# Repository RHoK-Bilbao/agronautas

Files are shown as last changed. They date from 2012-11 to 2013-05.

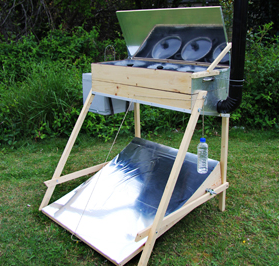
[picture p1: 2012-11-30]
software/web/assets/imgs/coc_demo.png

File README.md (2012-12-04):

RHoK-Bilbao 2012 (@rhokbilbao) project for ecologic solar cookers (Problem proposed by @pezestudio)

The solar cookers have an arduino board that connects to a central server to update information about its usage.

This information is then shared as Linked Open Data and visualized in a web interface 

!!!!!!!!!!!!!!!!!!!!!!!!!NOTE!!!!!!!!!!!!!!!!!!!!!!!!!!!!!!!!!

We have to upload still some of the code and the PCB designs. We hope to have them finished before christmass, be patient :-)

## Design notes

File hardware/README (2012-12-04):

This directory contains all the Arduino related files
	- agrococinas_sw contains the code for arduino
	- circuits contains all the PCB designs
	- models contains all the designs for the 3D printers
	
TODO: upload the models and PCB designs

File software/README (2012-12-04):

Non-Arduino software of the project.
	- lod contains the python server that receives the notificatios from the solar cookers. The servers converts this info to rdf and stores it in a Virtuoso server
	- web contains the web-interface for visualizing all the data

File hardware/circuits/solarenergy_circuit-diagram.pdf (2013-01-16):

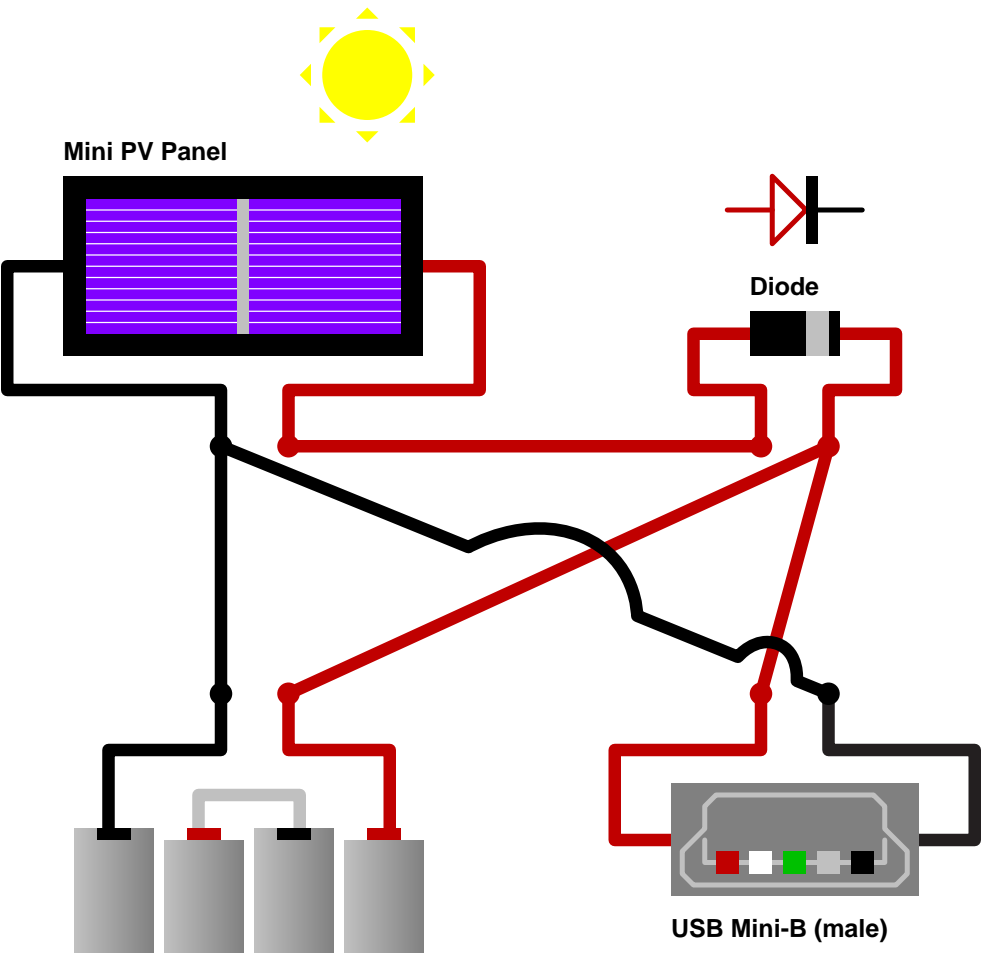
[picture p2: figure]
USB Mini-B (male); Mini PV Panel; Diode

NiMH DC Power Source

http://neotoy.tripod.com/
neotoy@hotmail.com

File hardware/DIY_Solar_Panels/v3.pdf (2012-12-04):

## Design v3.0

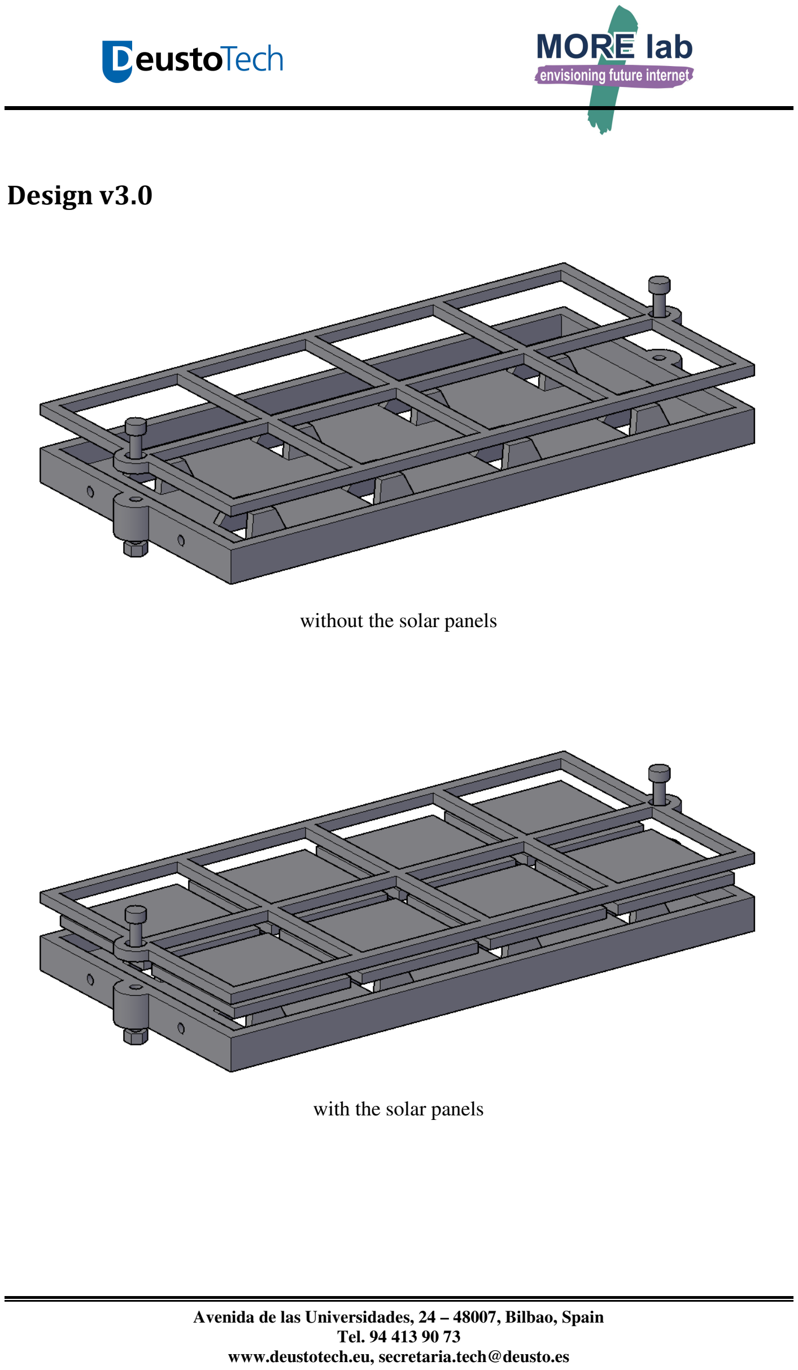
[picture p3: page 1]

Avenida de las Universidades, 24 – 48007, Bilbao, Spain Tel. 94 413 90 73
www.deustotech.eu, secretaria.tech@deusto.es

### without the solar panels

### with the solar panels

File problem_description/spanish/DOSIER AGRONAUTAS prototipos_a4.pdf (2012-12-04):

# agronautas

# pez

estudio

## Exploraciones entre personas y medio natural

un proyecto desarrollado por: | financia:

Juan
Dopico
Massobrio

+

## prototipos construidos

# proyectoagronautas

[AGRONAUTAS] es un proyecto multidisciplinar que investiga en procesos, diseños e iniciativas que reformulan la relación entre las personas y el medio natural.

+¿qué es?

+objetivos

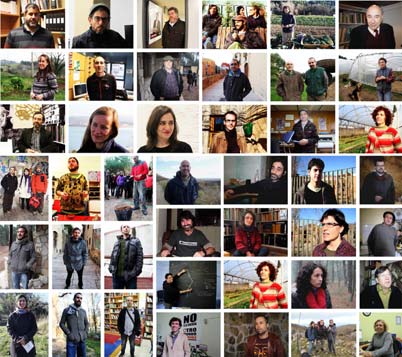
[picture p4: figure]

+herramientas

herramientas (cont.)

+Utilizar las tecnologías de la información, los recursos audiovisuales y medios digitales para socializar y extender modos de vida sostenible en los cuales se minimiza el consumo de energía y recursos.

+Poner en valor creaciones y modos de vida de profesionales y comunidades que, aunque representan avances en términos de sostenibilidad, no son normalmente visibles por la población.

+Realizar innovaciones en cuanto a minimización en consumo de recursos y energía a través de proyectos concretos y objetos o arquitecturas construidas.

o[EXPLORAR]
Se analizan y documentan iniciativas basadas en la minimización del impacto humano, así como del consumo de recursos y energía, en favor de un beneficio colectivo. Se trata de poner en valor proyectos que, pese a su interés, pueden pasar inadvertidos.

o[DESARROLLO AUDIOVISUAL]
A partir de la información recogida, se elaboran discursos audiovisuales que recojen experiencias y opiniones de los profesionales y colectivos entrevistados ,cuya actividad resulta muy interesante y, a veces, poco visible.
Se han documentado y registrado 40 experiencias colectivas, un total de 56 personas que desarrollan proyectos o modos de vida innovadores respecto al medio natural, a nivel individual, en comunidades o a través de su actividad profesional. En la primera etapa de exploración se ha realizado un documental recogiendo los mejores momentos de estas entrevistas.

o[TALLER COLABORATIVO]
Se desarrollan talleres constructivos para diseñar colaborativamente infraestructuras de beneficio colectivo en el marco de investigación del proyecto.
El primer taller constructivo dio lugar al primer prototipo de Agrococina, mobiliario compartido para huertas comunitarias y espacios exteriores.
Las infraestructuras se construyen en colaboración con comunidades que sean usuarios potenciales de lo construido, respondiendo a unas necesidades concretas.

o[EVALUAR]
Los prototipos se ponen en carga a través de los usuarios generados en la red del taller de construcción.

o[COMPARTIR]
Toda la información técnica y manuales se comparte en la red para que los prototipos sean evolucionados colectivamente. Agronautas abre un espacio físico y virtual de interacción.

o[AUTOGESTIONAR]
Las infraestructuras son totalmente asumidas y apropiadas por las comunidades que las adaptarán o modificarán según sus necesidades.

introducción

a

### Prototipos Construidos de

## agrococina

## ecomobiliario compartido

# pez

estudio

un proyecto desarrollado por: | financia:

Juan
Dopico
Massobrio

+

# agrococinabilbao 1

[AGROCOCINA] es un concepto de experiencia ecológica integral basado en el diseño de infraestructuras relacionadas con la arquitectura, la gastronomía, las artes culinarias, la ecología y la sociedad. El proyecto trabaja sobre el respeto al Medio Ambiente a través de los siguientes valores:
_Apoyar la producción ecológica y local, dando lugar a infraestructuras que faciliten y potencien estas prácticas. _Minimizar el uso de recursos en la construcción, utilizando metodologías y materiales de origen ecológico.
_Tender al gasto 0 de energía a través del desarrollo y mejora de sistemas y tecnologías renovables y novedosas. _Elaborar técnicas culinarias innovadoras, como recetas especialmente adecuadas al uso de fuentes de energía renovables.
_Potenciar la colectividad en torno a las experiencias relacionadas con la alimentación, la cocina y el acto de comer con diferentes grupos de personas y vinculando diferentes actividades.

El primer prototipo de Agrococina se concibió como un mobiliario completo diseñado para su uso en huertos comunitarios y pensado para ser reproducible de manera autoconstruida y evolucionada de forma colectiva.

Se construyó en Bilbao a través de sesiones previas con expertos y un taller colaborativo en el que se involucraron diferentes colectivos, usuarios de huertos colectivos de la ciudad y participantes.

El resultado ya ha empezado a ser utilizado y testado por distintos usuarios de diferentes huertos y asociaciones .
El prototipo incluye un sistema de monitorización vinculado a un software web que permite el almacenamiento y la compartición de datos en la red. El objetivo es realizar un seguimiento de éste y otros prototipos, permitiendo su comparación online y mejorarando su uso y diseño a lo largo del tiempo.
+¿qué es? | +primer prototipo | +testeo y monitorización

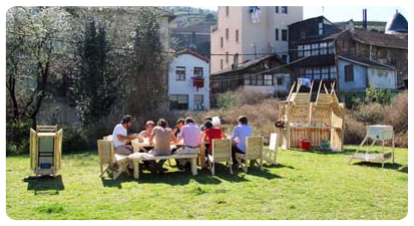
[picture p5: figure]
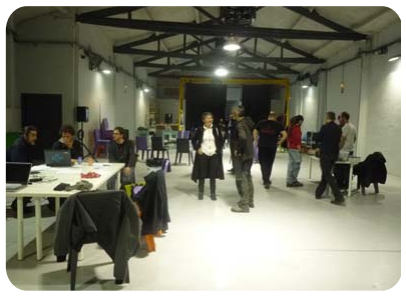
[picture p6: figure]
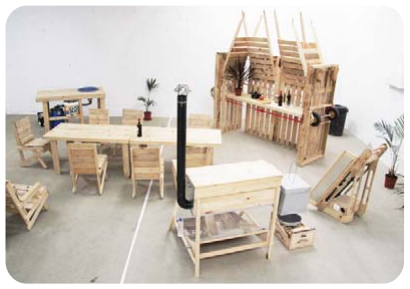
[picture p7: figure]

Para el diseño y construcción del primer prototipo, Pez[estudio] generó un equipo de trabajo multidisciplinar con expertos vinculados a los diferentes temas a desarrollar:

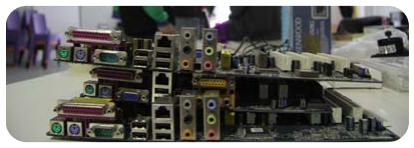
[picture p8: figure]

o[DISEÑO GLOBAL Y ORGANIZACIÓN]
+PEZ[estudio], | célula | creativa | de | arquitectura.
Desarrollamos proyectos de investigación, acción y diseño a diferentes escalas, con líneas de trabajo como la minimización de impacto sobre el medioambiente, la participación ciudadana o las técnicas y tecnologías no estandarizadas. http://www.pezestudio.org/

o[MÁQUINA DE COCINAR]
+TaerSolar es una empresa formada por especialistas en las nuevas tecnologías relacionadas con las energías renovables. http://www.taersolar.net/
+“Súper” es un experto reconocido a nivel internacional en
construcciones | sostenibles | y | de | energía | solar.
http://www.solarquedada.net/

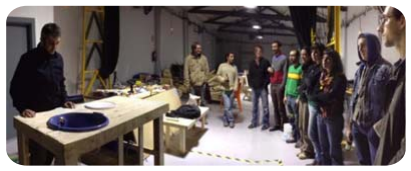
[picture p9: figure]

o[MOBILIARIO]
+Raumlabor berlin es un colectivo alemán que trabaja en la intersección entre la arquitectura, el planeamiento urbano, el arte y la intervención urbana. http://www.raumlabor.net

o[SISTEMA DE TRATAMIENTO Y DEPURACIÓN DE AGUA] +Mazetas desarrolla proyectos de arquitectura y paisaje con un enfoque ecológico sobre la gestión de los recursos y los residuos. http://mazetas.com/

o[ENERGÍA]
+Tuni Panea artista que especializado en electrónica, la música y el diseño. http://tunipanea.wordpress.com/(+Re:farm the city)

o[DISPOSITIVOS, WEB y VISUALIZACIÓN DE DATOS] +Re:farm the city provee de herramientas y conocimientos para diseñar, monitorizar, gestionar y compartir huertos urbanos. http://refarmthecity.org/

+equipo

# agronautas pez estudio

concepto

equipo (cont.)

### cocina-hornO SOLAR

### cocina-vapor solar

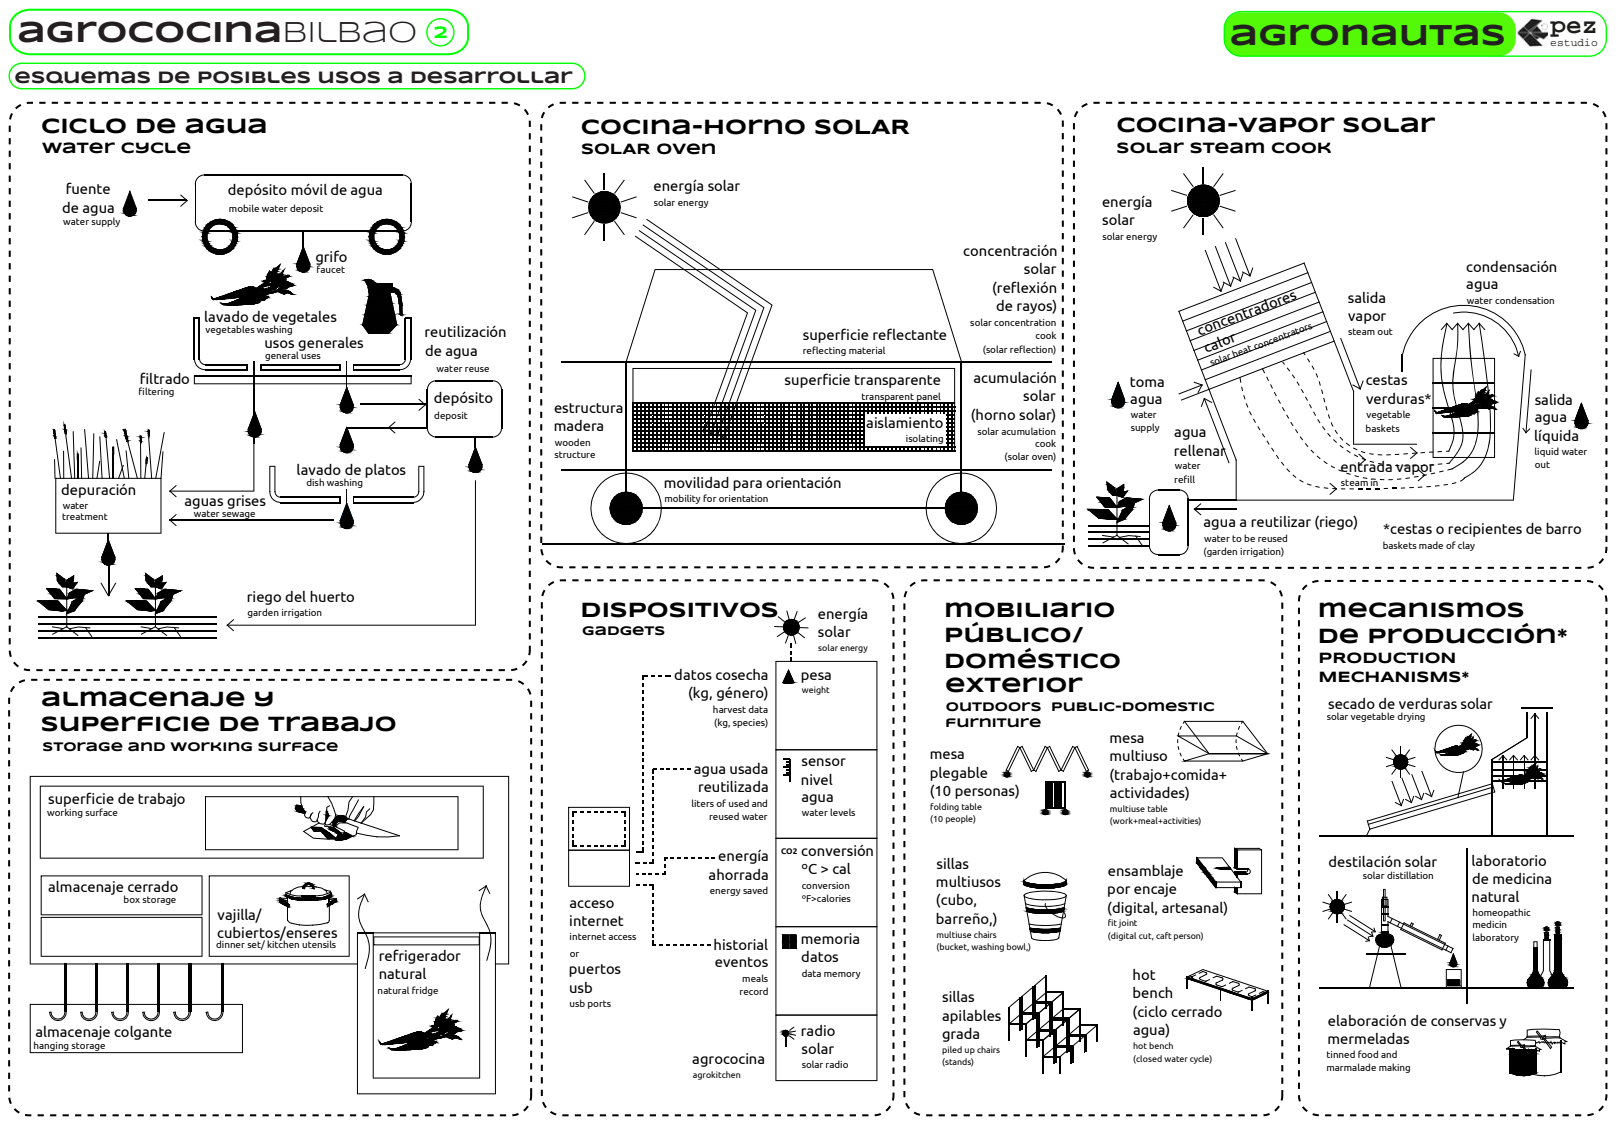
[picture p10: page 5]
SOLAR oven; energía solar; solar energy; acumulación solar (horno solar); concentración solar (reflexión de rayos); solar concentration cook (solar reflection); aislamiento; isolating; estructura madera; wooden structure; superficie transparente; transparent panel; superficie reflectante; reflecting material; toma agua; water supply; entrada vapor; steam in; cestas verduras*; vegetable baskets agua rellenar; water refill; salida agua líquida; liquid water out; condensación agua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

esquemas de posibles usos a desarrollar

ciclo de agua
water cycle

solar steam cook

depósito móvil de agua
mobile water deposit

concentradores calor solar heat concentrators salida vapor steam out

lavado de vegetales
vegetables washing

lavado de platos
dish washing

movilidad para orientación
mobility for orientation

agua a reutilizar (riego)
water to be reused
(garden irrigation)

*cestas o recipientes de barro
baskets made of clay

riego del huerto
garden irrigation

PRODUCTION
MECHANISMS*
secado de verduras solar
solar vegetable drying

almacenaje y
superficie de trabajo

storage and working surface

agua usada
reutilizada
liters of used and
reused water

working surface

multiuse table
(work+meal+activities)

vajilla/
cubiertos/enseres dinner set/ kitchen utensils

fit joint
(digital cut, caft person)

multiuse chairs
(bucket, washing bowl,)

elaboración de conservas y
mermeladas
tinned food and
marmalade making

piled up chairs
(stands)

hot bench
(closed water cycle)

agronautas | pez agrococinabilbao | estudio 3

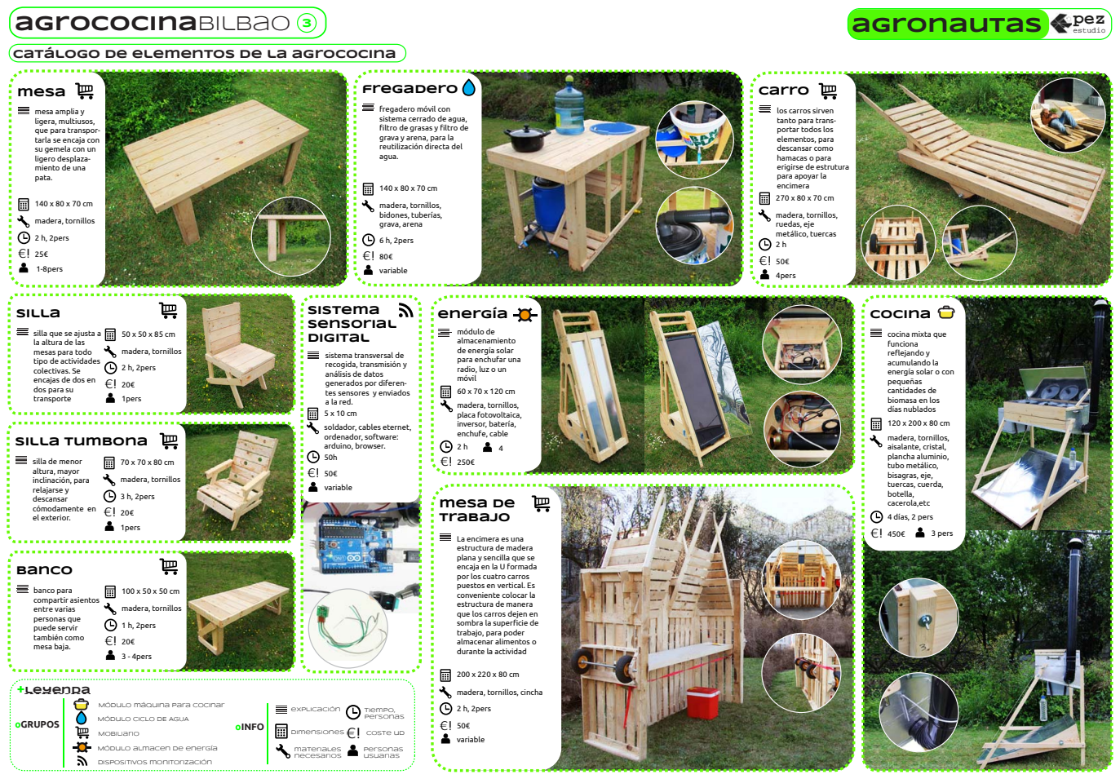
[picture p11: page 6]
carro; madera, tornillos, ruedas, eje metálico, tuercas 2 h; 4pers; mesa; madera, tornillos; 2 h, 2pers; 1-8pers; banco; 1 h, 2pers; 3 - 4pers; banco para compartir asientos entre varias personas que puede servir también como mesa baja.; fregadero; madera, tornillos, bidones, tuberías, grava, arena; 6 h, 2pers; variable; mesa de trabajo; madera, tornillos, cincha; cocina; 3 pers; energía; 4 silla tumbona; 3 h, 2pers; 1pers; silla; +leyenda; oGRUPOS; oINFO; materiales necesarios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

catálogo de elementos de la agrococina

mesa amplia y
ligera, multiusos,
que para transpor-
tarla se encaja con
su gemela con un
ligero desplaza-
miento de una
pata.

fregadero móvil con
sistema cerrado de agua,
filtro de grasas y filtro de
grava y arena, para la
reutilización directa del
agua.

los carros sirven
tanto para trans-
portar todos los
elementos, para
descansar como
hamacas o para
erigirse de estrutura
para apoyar la
encimera

silla que se ajusta a
la altura de las
mesas para todo
tipo de actividades
colectivas. Se
encajas de dos en
dos para su
transporte

módulo de
almacenamiento
de energía solar
para enchufar una
radio, luz o un
móvil
madera, tornillos,
placa fotovoltaica,
inversor, batería,
enchufe, cable

cocina mixta que
funciona
reflejando y
acumulando la
energía solar o con
pequeñas
cantidades de
biomasa en los
días nublados
aisalante, cristal,
plancha aluminio,
tubo metálico,
bisagras, eje,
tuercas, cuerda,
botella,
cacerola,etc
4 días, 2 pers

sistema transversal de
recogida, transmisión y
análisis de datos
generados por diferen-
tes sensores y enviados
a la red.
soldador, cables eternet,
ordenador, software:
arduino, browser.
variable

silla de menor
altura, mayor
inclinación, para
relajarse y
descansar
cómodamente en
el exterior.

La encimera es una
estructura de madera
plana y sencilla que se
encaja en la U formada
por los cuatro carros
puestos en vertical. Es
conveniente colocar la
estructura de manera
que los carros dejen en
sombra la superficie de
trabajo, para poder
almacenar alimentos o
durante la actividad

Módulo máquina para cocinar

Módulo CICLO DE AGUA

Módulo almacen de energía

# agronautas pez estudio agrococinabilbao

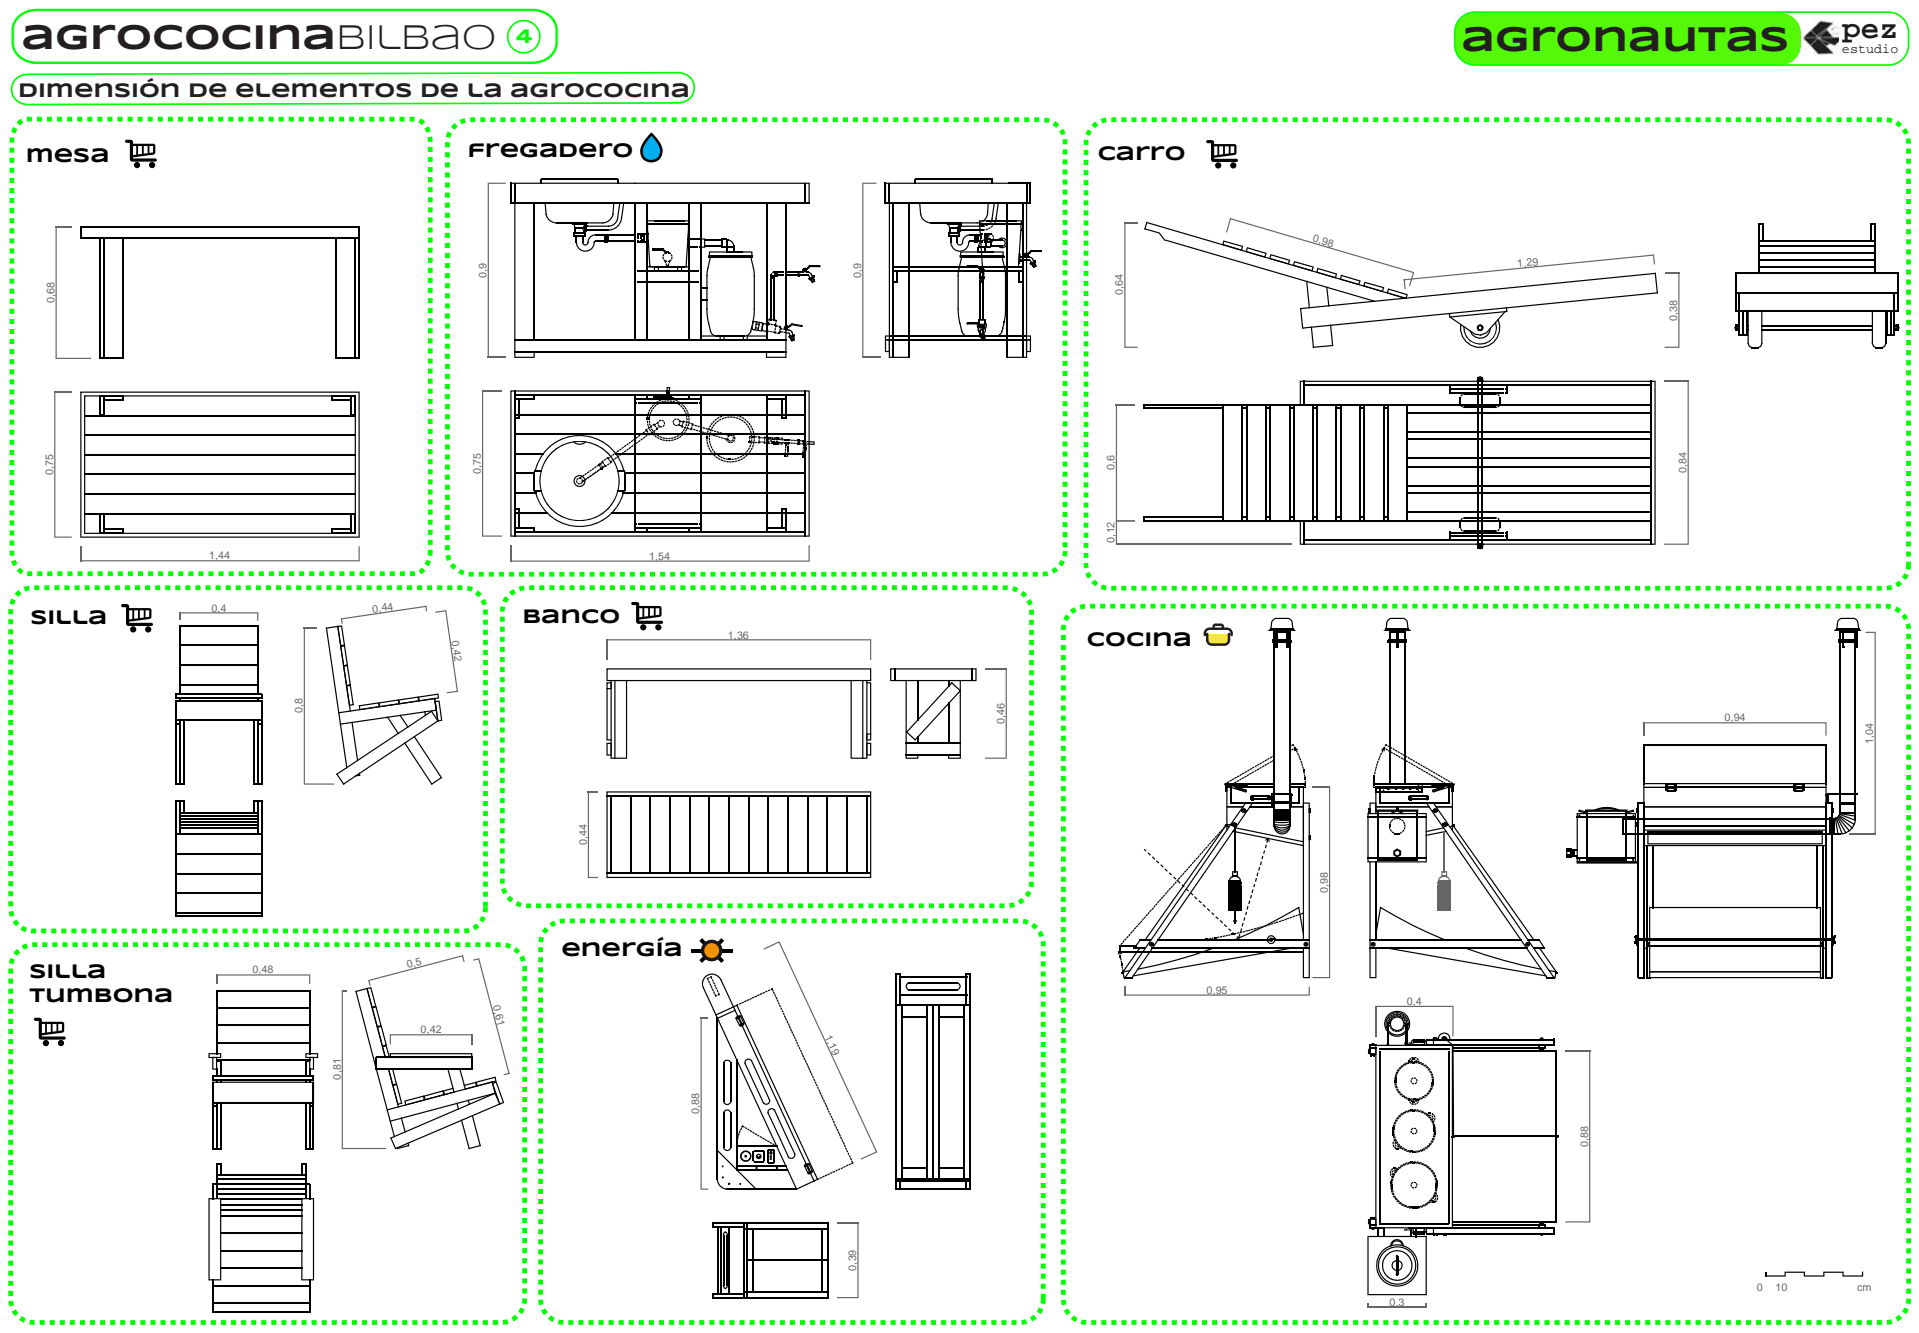
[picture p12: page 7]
mesa; carro; banco; fregadero; cocina; energía; silla tumbona; silla

dimensión de elementos de la agrococina

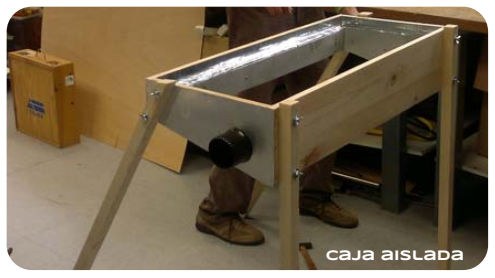
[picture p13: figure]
caja aislada

taller 01

evento 01

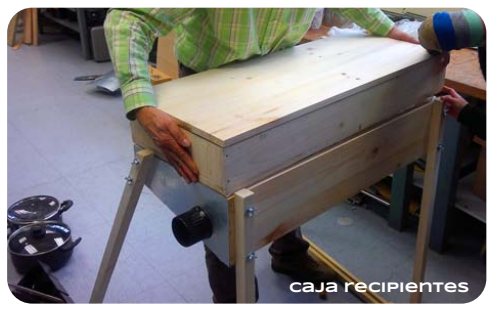
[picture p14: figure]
caja recipientes
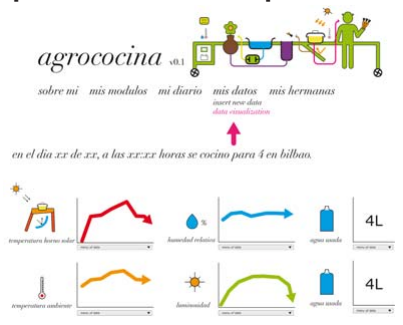
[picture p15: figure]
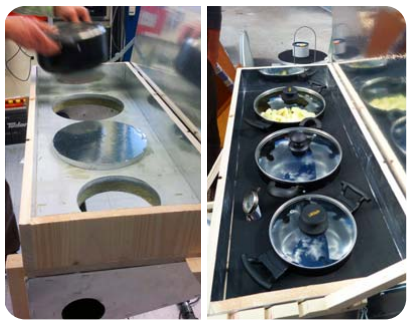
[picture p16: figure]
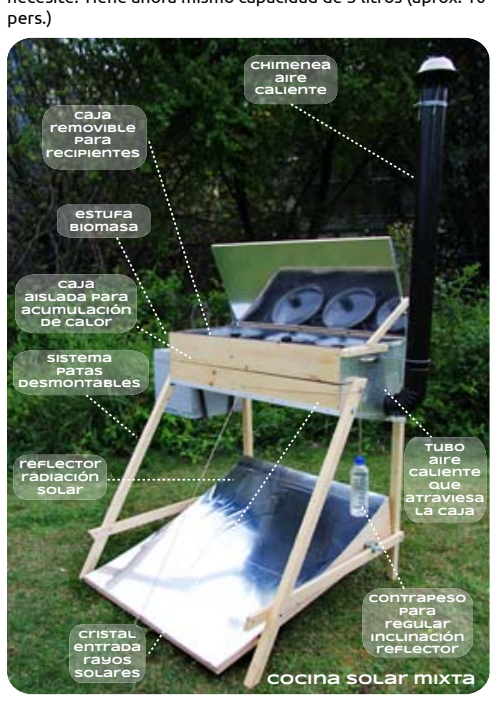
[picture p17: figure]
pers.); cocina solar mixta; sistema patas desmontables; contrapeso para regular inclinación reflector; cristal entrada rayos solares; tubo aire caliente que atraviesa la caja; caja aislada para acumulación de calor; estufa biomasa; chimenea aire caliente; reflector radiación solar; caja removible para recipientes

evento 02

+módulo de cocina | +sistema monitorizacion | +web y recogida de datos

El módulo de cocina es un prototipo de cocina solar mixta,
que funciona como un horno solar invertido (cara inferior
transparente) para tener la posibilidad de manipular los
alimentos. Posee una caldera de biomasa optimizada y adaptada para los días menos calientes.

o[ELEMENTOS]
La cocina tiene las siguientes partes:
>Caja de madera aislada en sus cuatro laterales y con la cara inferior de cristal
>Caja de madera aislada en su cara inferior donde se encajan los recipientes para cocina, la tapa sirve para aislar más
>Reflector parabólico lineal regulable
>Contrapeso para la regulación de inclinación del reflector >Estufa de biomasa con tiro regulable, y aislada para optimizar el gasto
>Tubo de aire caliente que atraviesa longitudinalmente
la caja aislada de madera.
>Chimenea para salida de humos y aire caliente
>Sistema de patas fijadas con uniones roscadas (palometas)

o[USOS]
La caja superior removible tiene la cara inferior reemplazable para poder adaptar el recipiente que se necesite. Tiene ahora mismo capacidad de 3 litros (aprox. 10

El módulo de cocina tiene adaptado un sistema de monitorización, que llamamos “Sistema Sensorial Digital” que consiste en un sistema transversal de recogida, transmisión y análisis de datos generados por diferentes sensores colocados en diferentes puntos de la cocina y enviados a la red.
La principal finalidad del “Sistema Sensorial Digital” es el análisis de la eficiencia de la cocina con el objetivo de optimizar su funcionamiento, auqnue aún se encuentra en versión beta.

o[ELEMENTOS]
El “Sistema Sensorial Digital” consta de los siguientes elementos:
>Una placa Arduino
>Sensores :
_Humedad HIH 4030 integrated circuit humidity sensor _Luminosidad. TEMT6000 Ambient Light Sensor _Temperatura exterior. LM35CZ IC Temperature Sensing Range: -40°C to +110°C
_Temperatura interior. LM35CZ IC Temperature Sensing Range:+2°C to +100°C
>Una web dinámica ligada a una base de datos

o[FUNCIONAMIENTO]
La información obtenida se registra en la placa Arduino cada 5 min. Esto significa que el sistema permite guardar hasta 10 horas de datos.

El “Sistema Sensorial Digital” está compuesto por una placa Arduino, varios sensores y una interfaz web ligada a una base de datos.

Los datos recogidos se pueden visualizar automáticamente a través de la web y realizar comparativas temporales o espaciales. Adicionalmente, una vez que se hayan introducidos una cantidad de datos significativa, el sistema podrá realizar predicciones de funcionamiento según determinadas variables.

o[ESQUEMA SENSORES para TOMA DE DATOS]

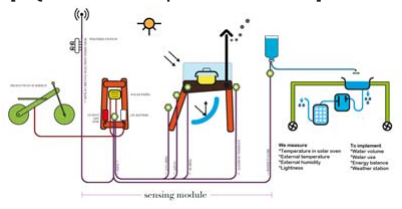
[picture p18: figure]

o[WEB con VISUALIZACIÓN DE DATOS] funcionamiento elementos de la agrococina

agronautas | pez agrococinabilbao | estudio 5

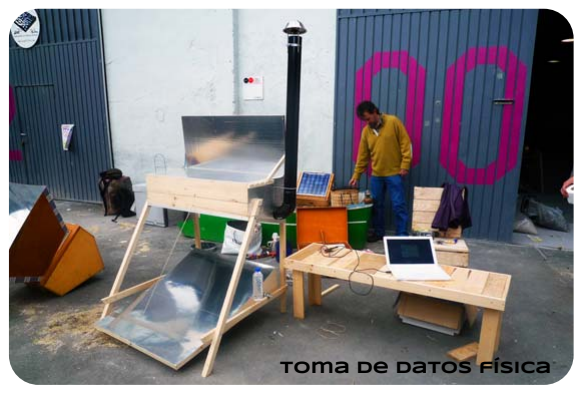
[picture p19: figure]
toma de datos física
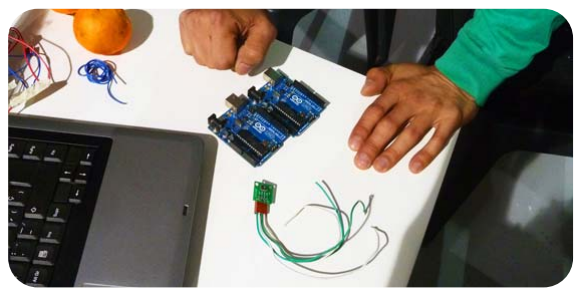
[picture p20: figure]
evento 04
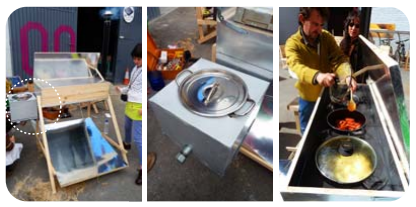
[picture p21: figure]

agronautas | pez agrococinabilbao | estudio 6

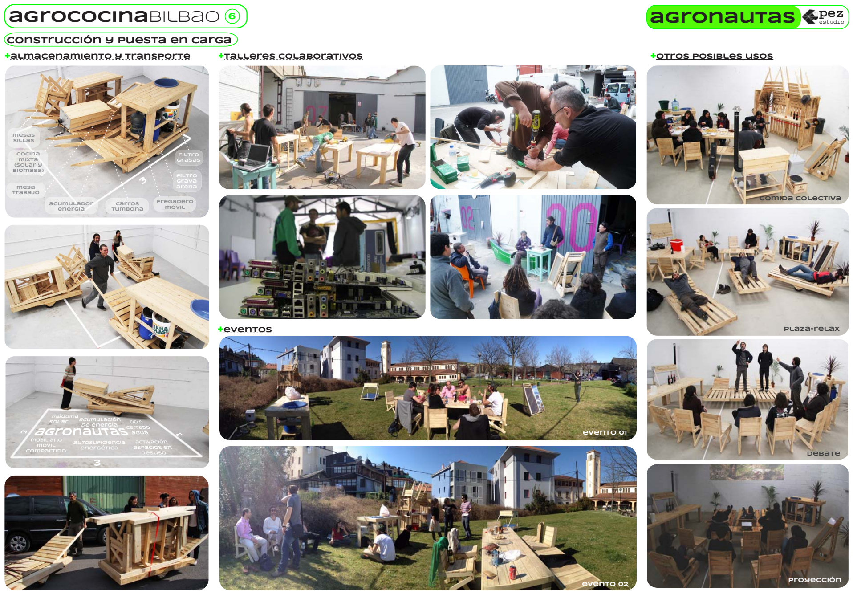
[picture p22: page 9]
evento 01; evento 02; filtro grasas; fregadero móvil; filtro grava arena; cocina mixta (solar y biomasa); mesas sillas; carros tumbona; acumulador energía; mesa trabajo; comida colectiva; plaza-relax; debate; proyección; +almacenamiento y transporte; +talleres colaborativos; +eventos

construcción y puesta en carga

+otros posibles usos

a

### Prototipos Construidos de

## ciclo-remolques equipados

## ecomobiliario compartido

# pez

estudio

un proyecto desarrollado por: | financia:

cicloremolquesequipadosbcn 1 | agronautas | pez estudio

La propuesta consiste en construir e iniciar una autogestión de mobiliario compartido con los vecinos de Ciutat Vella; respondiendo a necesidades colectivas concretas en el espacio público, y reactivando espacios vacíos disponibles de la ciudad. El punto de partida serán las infraestructuras del catálogo de la Agrococina, adaptándolas y evolucionándolas. Se hará un taller de construcción participativo para generar mobiliario acordado con las asociaciones, grupos y colectivos interesados. Los prototipos, una vez finalizado el taller, serán posteriormente apropiadas y gestionadas por los vecinos.

A través del análisis del barrio se detectaron distintos grupos activos y organizados que compartían actividades e intereses: huertos urbanos en el centro de Barcelona. Las necesidades de estos espacios eran muchas, así que se trabajó para cubrir algunas de las necesidades expresadas.

Se diseñaron infraestructuras que además de complementar las actividades existentes, dirigían hacia una gestión entre toda la comunidad de huertos urbanos. Las características del barrio favorecían la gestión conjunta y el transporte de las infraestructuras.

El resultado fueron dos prototipos de remolques equipados para ser transportados por una sola persona en bicicleta.
Los objetivos marcados fueron:
_Potenciar el intercambio de conocimientos y experiencias entre los agentes relacionados con los huertos urbanos para fortalecer la red ya existente.
_Hacer posible la realización de actividades relacionadas con los huertos en otros espacio públicos para su difusión. _Generar un diseño en que el propio uso de las infraestructuras provocara un uso mínimo de recursos

oANÁLISIS CRÍTICO CIUDADANO: TALLER RESPUESTA A NECESIDADES EXPUESTAS POR LOS VECINOS
El primer paso es conocer las redes ya existentes. Iniciar un diálogo para conocer su realidad, la problemática real y poder dar una respuesta constructiva que trabaje sobre esas dinámicas detectadas. La metodología
establecida trata de diseñar un proceso de construcción participativa a partir de unas necesidades detectadas o cristalizadas durante el diálogo.

oFIJAR OBJETIVOS: ESTABLECIMIENTO DE LÍNEAS DE TRABAJO
Una vez establecido el diálogo con las organizaciones o grupos del barrio, se fijan las líneas de trabajo asociadas a elementos contruidos que se van a desarrollar. Se establecen disponibilidades, herramientas y lugares de trabajo.

oTALLER ABIERTO: SOCIOS LOCALES
Se intentará involucrar a expertos, ciudadanos o colectivos relacionados de Barcelona, aparte de lxs vecinxs y asociaciones, que quieran colaborar en el proceso de construcción de infraestructuras durante el taller.

oORGANIZACIÓN DE DINÁMICAS: FORMACIÓN DE GRUPOS DE TRABAJO
Además de localizar recursos en el propio barrio, se buscarán colaboradores con los que establecer cierto intercambio. Se trabajará en grupos, cada grupo desarrollará un tema asociado a un prototipo constructivo, de acuerdo a los recursos encontrados.

oCONSTRUCCIÓN PARTICIPATIVA: RED LOCAL DE AUTO-CONSTRUCCIÓN y RECURSOS
El taller se plantea como un testeo de metodologías para generar infraestructuras físicas, incitando al conocimiento del barrio y sus recursos, materiales y humanos, reforzando vínculos que hagan que los vecinos puedan pensar y autogestionar infraestructuras para su barrio.

oGESTIÓN MOBILIARIO: ESPACIO PÚBLICO ACTIVADO El mobiliario que resulte del taller será un bien común, y se tendrá que diseñar su forma de gestión. Si los participantes no se apropiaran de las infraestructuras construidas se abrirá un período posterior para solicitar el mobiliario.

PROPUESTA TALLER

+¿qué?

El lugar de reunión y trabajo para el Taller se fijará con los participantes y la organización. Proponemos como mejor opción realizarlo en uno de los solares vacíos del barrio, que son lugares visibles, accesible y a apropiables por los vecinos.

+¿dónde?

Durante el mes anterior al Festival Eme3 se publicitará el taller a través de medios locales. Durante este mes se establecerá un canal de comunicación virtual para ir coordinando a los interesados, fijando las necesidades posibles a cubrir, la implicación de cada colectivo y la organización previa. Al final de esta etapa ya se habrá formado un grupo de participantes que construirán el mobiliario junto con dos miembros de Pezestudio.
La puesta en carga del mobiliario se hará a través de un evento abierto y colectivo en un espacio exterior del barrio.

+¿cómo?

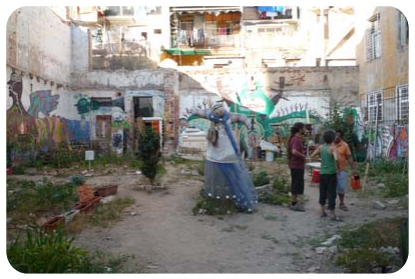
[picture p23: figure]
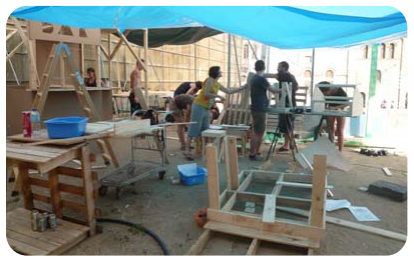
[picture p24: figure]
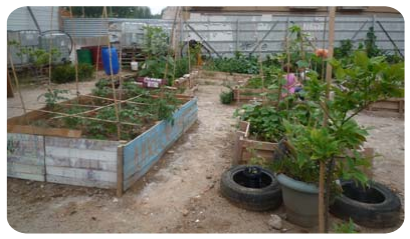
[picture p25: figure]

El taller estará abierto a cualquier interesado en mobiliario ecológico, compartido, autoconstruido y autogestionado. Serán especialmente bienvenidos los participantes que quieran generar infraestructuras para usos comunitarios.

+¿quiénes?

+pautas planteadas | +resultados

03 C. RIERETA /
C. SANT RAFAEL

01 PORTAL
SANTA
MADRONA

area 649,3 m2

area 777 m2

area 596,8 m2

area 84,7 m2

04 C. SANT PERE
MES BAIX
C. METGES

area 56,1 m2

05 C. BANYS VELLS
C. BROSOLI

area 65,6 m2

06 C. CANVIS NOUS
C. CONSELLERS

area 39 m2

02 C. RIERETA
C. SANT PAU

RECLAMAN RECLAMAN
ZONAS VERDES ZONAS VERDES
EQUIPAMIENTOS EQUIPAMIENTOS SOCIALES Y SOCIALES Y
ESCUELAS ESCUELAS

EXISTE ZONA EXISTE ZONA
DE JUEGOS DE JUEGOS

CANCHA FÚTBOL CANCHA FÚTBOL PING-PONG PING-PONG

RUIDO POR RUIDO POR
LAS NOCHES LAS NOCHES

JARDÍN NATURAL JARDÍN NATURAL ABANDONADO ABANDONADO

ZONA TURÍSTICA ZONA TURÍSTICA TRÁNSITO TRÁNSITO

ASAMBLEA EL FORAT ASAMBLEA EL FORAT HUERTO COMUNITARIO HUERTO COMUNITARIO

CANCHAS CANCHAS
TARIMA CULTURAL TARIMA CULTURAL

EXISTE ZONA EXISTE ZONA
DE JUEGOS DE JUEGOS

ESPACIO PÚBLICO ESPACIO PÚBLICO OCUPADO POR OCUPADO POR
DESCONOCIDOS DESCONOCIDOS

culturas
predominantes:
*chinxs
*senegalesxs
*marroquís
*italianxs

*pakistanís
*dominicanxs
*ecuatorianxs

culturas
predominantes:

festival
eme3
(coac)

metodología

### BARRIO RIBERA

### MATERIALES MOBILIARIO COMPARTIDO AUTOCONSTRUIDO Y AUTOGESTIONADO

REUTILIZACIÓN

POBLACIÓN
JOVEN

ESPACIO
PÚBLICO
DISPONIBLE

ASOCIACIONES
COLECTIVOS
LOCALES

ARTESANOS
LOCALES

ARTISTAS
EXPERTOS

ARQUITECTOS
ESTUDIANTES
ACTIVISTAS

AGENTES LOCALES
EXPERIENCIA

POBLACIÓN
JUBILADOS

### BARRIOS

+DINÁMICAS
+PROBLEMÁTICAS
+RECURSOS

### muchas mujeres mayores de 65años que viven solas BARRIO EL RAVAL

REACTIVACIÓN ESPACIOS
PÚBLICOS DE
CIUTAT VELLA CON
INFRAESTRUCTURAS ECOLÓGICAS

# agronautas pez estudio

+FASE 0

oPREVIO AL TALLER:
contacto con POSIBLES FUTUROS USUARIOS conexión PREVIA con agentes locales

+grupos sociales organizados locales +asociaciones vecinales
+asociaciones culturales
+asociaciones relacionadas ecología
+....

*objetivos:
*información de la iniciativa en círculos externos a eme3
*generación o inserción en la red/redes sociales y de uso del espacio público ya establecidas
*contraste con opiniones locales sobre la propuesta

+FASE 1

oJORNADA 1:
reunión y toma de decisiones para el desarrollo del mobiliario compartido

DECISIÓN COLECTIVA

+presentación de la propuesta
+detección de necesidades locales +posibles usos del mobiliario compartido +selección de elementos a desarrollar a partir del catálogo propuesto
+posibles modificaciones sobre las propuestas del catálogo
*objetivos:
*decisión del planteamiento de acuerdo a las necesidades y futuros usos de participantes en el taller y población local

+FASE 2

oJORNADAS 2-5:
organización y construcción colectiva del mobiliario

taller de construcción
participado

+Organización en grupos, según las áreas de conocimiento o interés, y según mobiliario a desarrollar: -mobiliario
-cocina solar
-sistema de agua
-captación de energía
-electrónica
+Ejecución de las piezas de mobiliario
+Puestas en común de avances y necesidades diarios *objetivos:
*construcción completa del mobiliario *generación de equipo/comunidad
*aprendizaje de jerarquía horizontal entre los participantes

+FASE 3

oJORNADA 6:
inauguración del mobiliario y decisión sobre su futura gestión

gestión futura del
mobiliario compartido

+Decisión y preparación de actividad de inauguración en relación con el prototipo de mobiliario realizado. +Reunión con agentes para la decisión sobre el modo de gestión:
-compartición: modo y organización -permanencia en uno de los solares -gestionado por sola asociación/grupo que distribuye al resto
*objetivos:
*consensuar el modo de gestión futura del mobiliario, que permita su disfrute óptimo.

posibles futuros usos del mobiliario compartido

+FASE 4

Agrococina completa:
comidas colectivas

Asambleas y reuniones de decisión Transporte oFUTURO DESPUÉS DEL TALLER:
utilización de diferentes formas según el mobiliario construido. Dejamos aquí sólo algunos ejemplos

LA GENERACIÓN DE UN MOBILIARIO REALMENTE MÓVL
PERMITIRÍA ESTABLECER UN
FUTURO ITINERARIO DE USO.

MOVILIDAD:

el mobiliario
podría rotar
entre los
diferentes
solares

# cicloremolquesequipadosbcn

2

agronautas | pez cicloremolquesequipadosbcn 3 | estudio

prototipos; horno solar + sistema filtrado; madera, tornillos, cristal, cartón, bidones, tuberías, ruedas bici; 3días, 4pers; variable; oINFO; materiales necesarios; tiempo, personas; personas usuarias explicación; dimensiones; €! coste ud; mini huerto + mobiliario; madera, tornillos, bidones, tuberías, ruedas bici; 2 días, 3pers

horno solar móvil con
sistema cerrado de agua,
con filtro de grasas para
la reutilización directa
del agua.

Módulo con cajones para
almacenaje de planto-
nes, semillas y
herramientas de
plantado, que contiene
mobiliario para talleres y
encuentros

pez[estudio]; agronautas; han colaborado:; han participado:; Tunipanea; Huertos Eco-Comunitarios de Lutxana; Agradecemos a:; ZAWP; Hort del Xino; Huerto de Poblenou

Taller de Construcción del Primer Prototipo de Agrococina

Taller de Construcción de Prototipos de Ciclo-remolques equipados

Todos los participantes del Eme3 que colaboraron en el taller, en especial a

Jaime, Íñigo, Marc, Blanca y Laura

Raumlabor berlin
www.raumlabor.net

Re:Farm the City
refarmthecity.org

Mazetas
www.mazetas.com

Hort Fort del Pienc
hortpienc.blogspot.com/

hortdelxino.wordpress.com/

Jose M. Jiménez “Súper”
www.solarquedada.net

TaerSolar
www.taersolar.net

L´Hortet del Forat
lhortetdelforat.blogspot.com/

Asociación La Lleonera
lalleonera.es/

tunipanea.wordpress.com

Ur-Chi-Tao
Huerto Colectivo

y muchos participantes más

Re-Cooperar
recooperar.blogspot.com/

The Institute of Placemaking
facebook.com/TheInstituteOfPlacemaking

Baratza Taldea Deustuko
Ortu Kooperatiboa
baratzataldea.blogspot.com

Manuel Vilechez
www.alsol.com

www.zawpbilbao.com

www.pezestudio.org
info@pezestudio.org

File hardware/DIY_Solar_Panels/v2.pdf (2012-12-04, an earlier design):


Avenida de las Universidades, 24 – 48007, Bilbao, Spain Tel. 94 413 90 73
www.deustotech.eu, secretaria.tech@deusto.es

## Design v2.0

### without the solar panels

### with the solar panels

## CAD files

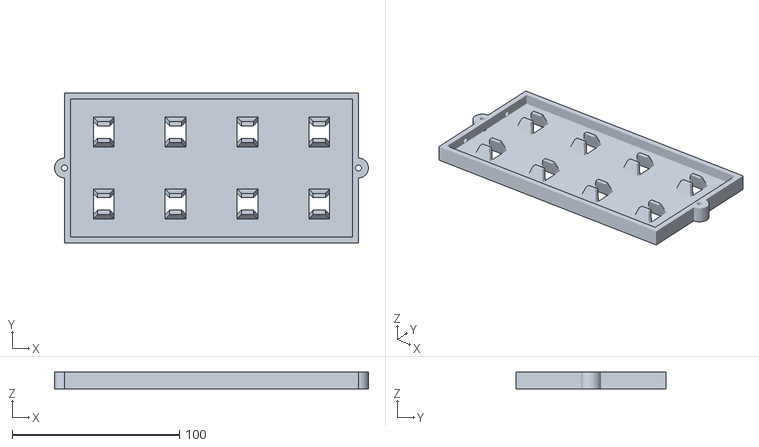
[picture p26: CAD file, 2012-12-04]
hardware/DIY_Solar_Panels/design v3.2.stl
188.0 x 90.0 x 10.00

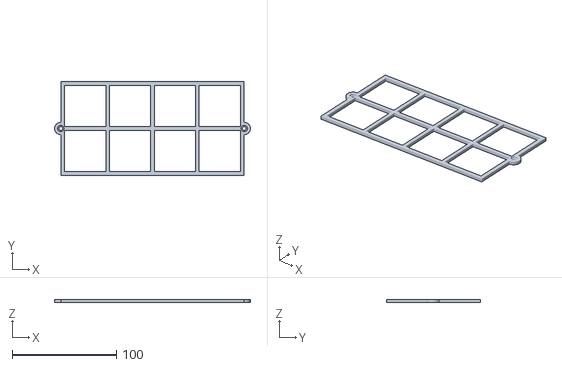
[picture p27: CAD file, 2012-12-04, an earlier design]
hardware/DIY_Solar_Panels/design v3.1.stl
188.0 x 90.0 x 3.00

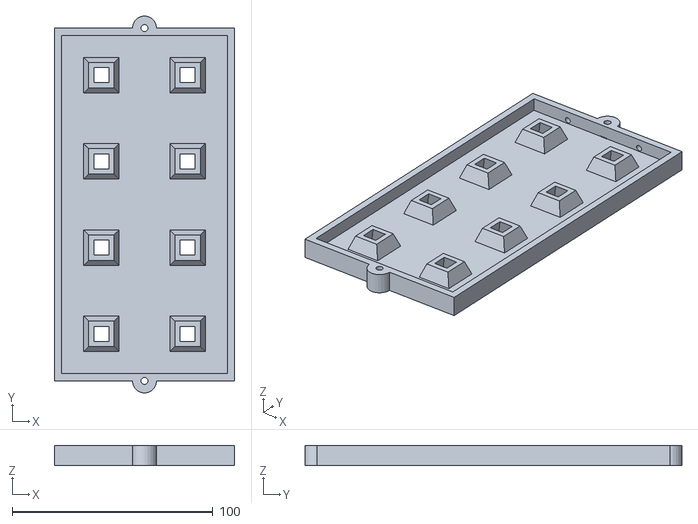
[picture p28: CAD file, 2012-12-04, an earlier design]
hardware/DIY_Solar_Panels/design v2.2.stl
90.0 x 188.0 x 10.00

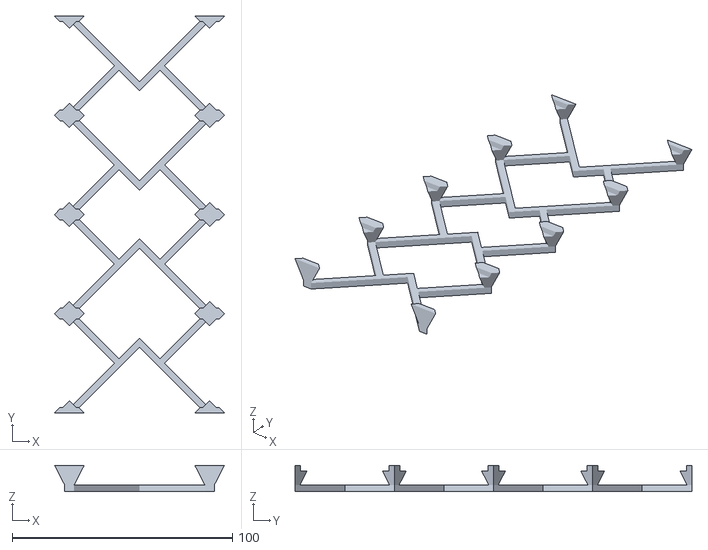
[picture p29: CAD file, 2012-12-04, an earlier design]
hardware/DIY_Solar_Panels/design v1.0.stl
77.1 x 180.0 x 12.0

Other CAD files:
hardware/DIY_Solar_Panels/design v3.0.dwg
hardware/DIY_Solar_Panels/design v2.0.dwg
hardware/DIY_Solar_Panels/design v2.1.stl
hardware/DIY_Solar_Panels/design v1.0.dwg

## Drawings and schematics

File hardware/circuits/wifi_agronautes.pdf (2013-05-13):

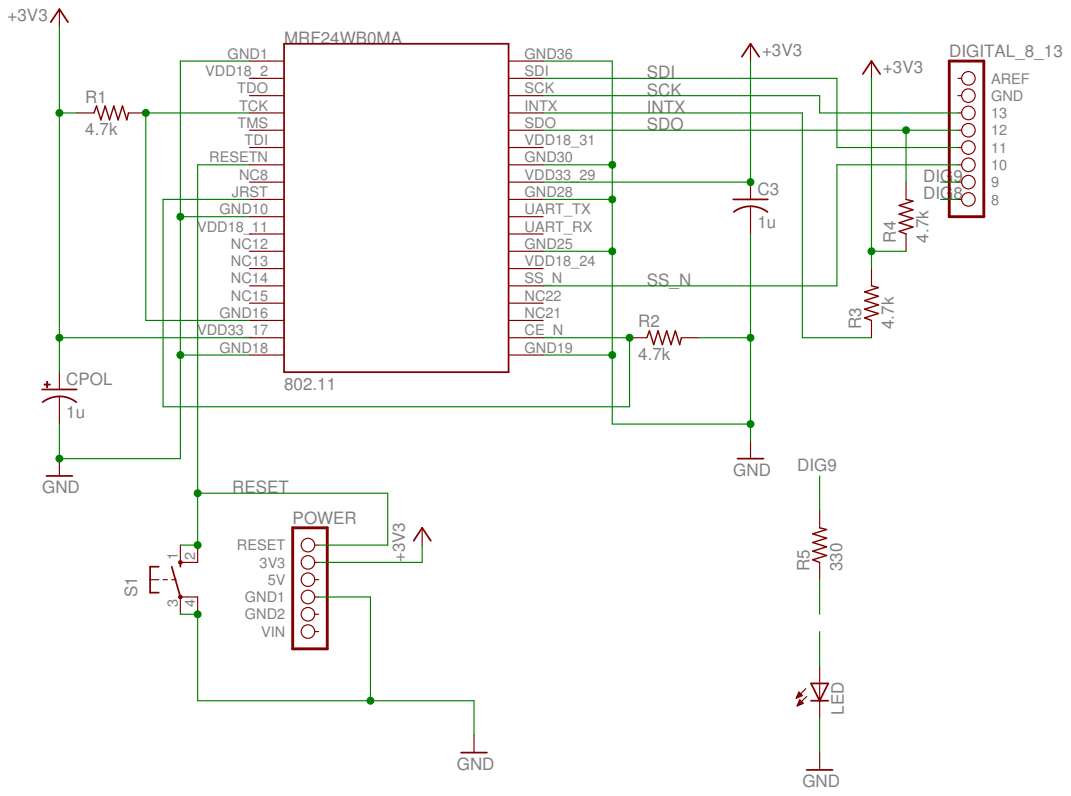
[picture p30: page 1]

GND1 VDD18_2 TDO TCK TMS TDI RESETN | GND36 SDI SCK

SCK

INTX | INTX
SDO | SDO

13/05/13 11:51 /home/dieguich/Escritorio/wifi_agronautes.sch (Sheet: 1/1)

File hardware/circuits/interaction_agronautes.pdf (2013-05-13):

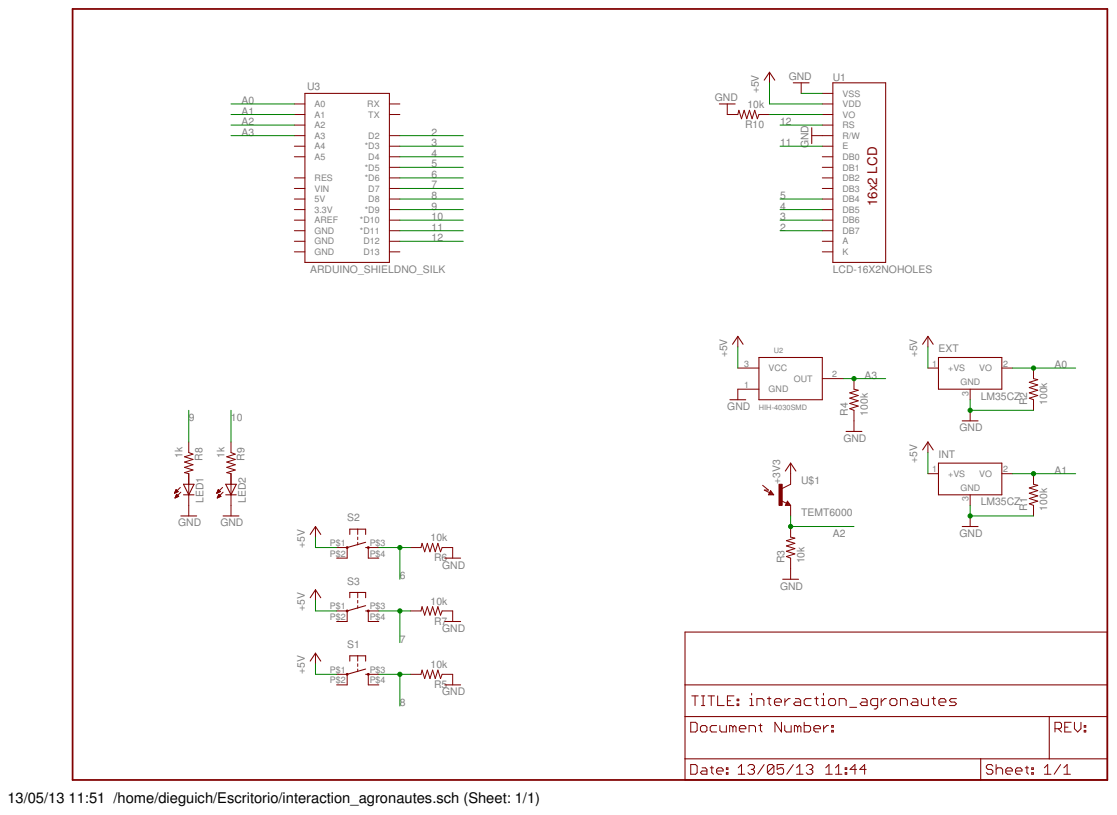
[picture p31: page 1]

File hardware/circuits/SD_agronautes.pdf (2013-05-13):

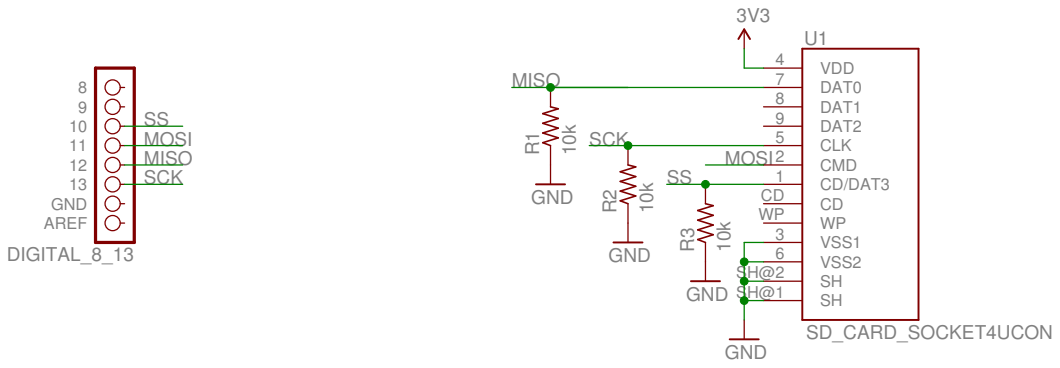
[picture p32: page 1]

13/05/13 11:51 /home/dieguich/Escritorio/SD_agronautes.sch (Sheet: 1/1)

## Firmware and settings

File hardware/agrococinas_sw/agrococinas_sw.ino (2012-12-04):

// Includes
#include <EEPROM.h>
#include <SdFat.h>
#include <LiquidCrystal.h>

// declare variables
SdFat sd;
SdFile myFile;
const int chipSelect = 53;
float tempInC;
float humedC;
float luminC;
float tempOutC;
char* luminL;
boolean advicedHighTemp = false;
// initialize the library with the numbers of the interface pins
LiquidCrystal lcd(12,11, 5, 4, 3, 2);
//buttons
const int bDataPin = 0;
const int bStartPin = 6;
const int bFinishPin = 1;
int bDataState = 1;
int bStartState = 1;
int bFinishState = 1;
int showState = 0;
//timestamp
long int timestampBegin = 0;
long int timestampIntermediate = 0;
long int timestampFinish = 0;
int stage = 0; //0:not oriented; 1:oriented and heating; 2:cooking; 
//sensors
int tempInPin = A0;
int humedPin = A1;
int luminPin = A2;
int tempOutPin = A3;
int led = 7;
int samples[8]; // 8 samples to have a large sample
//EPROMM Write
int addr = 0;
int addr1 = 0;
int addr2 = 0;
int addr3 = 0;
// constants and aux
float supplyVolt = 5.0;
int temp_warning = 22;
char* msg = "";
char* kitchen_name = "kitchen_1";
char aux_string[40];


void setup()
{
  Serial.begin(115200); //opens serial port, sets data rate to 115200 bps
  pinMode(led, OUTPUT);//led pin as output   
  //clean the EEPROM
  for (int i = 0; i < 512; i++)
    EEPROM.write(i, 0);
  pinMode(bStartPin, INPUT); 
  pinMode(bFinishPin, INPUT);
  pinMode(bDataPin, INPUT);  
  // set up the LCD's number of columns and rows: 
  lcd.begin(20, 4);
  // Print a message to the LCD.
  lcd.setCursor(0, 0);
  lcd.print("direct me towards the sun and");
  lcd.setCursor(0, 2);
  lcd.print("press green button");   
}

void writeSD(){
if (!sd.begin(chipSelect, SPI_HALF_SPEED)) sd.initErrorHalt();
  // open the file for write at end like the Native SD library
  if (!myFile.open("log.txt", O_RDWR | O_CREAT | O_AT_END)) {
    sd.errorHalt("write failed");
  }
  myFile.println();
  myFile.print("Outside temperature: ");
  myFile.print(tempOutC,0); 
  myFile.println();
  myFile.print("Luminosity: ");
  myFile.print(luminC, 0); 
  myFile.print("  ");
  myFile.print(luminL);
  myFile.println();
  myFile.print("Humidity: ");
  myFile.print(humedC,0);
  myFile.println();
  myFile.print("Inside temperatura: ");
  myFile.print(tempInC,0);  
  myFile.println();
  // close the file:
  myFile.close();
  Serial.println("done.");
}

void readSD(){
  if (!sd.begin(chipSelect, SPI_HALF_SPEED)) sd.initErrorHalt();
  // re-open the file for reading:
  if (!myFile.open("log.txt", O_READ)) {
    sd.errorHalt("read failed");
  }
  Serial.println("log.txt:");
  // read from the file until there's nothing else in it:
  int data;
  while ((data = myFile.read()) > 0) Serial.write(data);
  // close the file:
  myFile.close();
}

void evaluate_temp()
{
  Serial.println(tempOutC);
  Serial.println(temp_warning);
  if(tempOutC> temp_warning){
    Serial.print("Temperature over ");
    Serial.println(temp_warning);
    digitalWrite(led, HIGH); 
  }else{
     digitalWrite(led, LOW); 
  }
}

void evaluate_lumi()
{
  if(luminC < 75){
    luminL = "very dark";
  }else if(luminC < 150){
    luminL = "dark";
  }else if(luminC < 225){
    luminL = "bright";
  }else{
    luminL = "very bright";
  } 
}

void generateUpdate()
{
  //aux variables
  char at[2]="@";
  char aux[10];
  //build the string for sending via WiFi
  memcpy(aux_string,"UPDATE@",7); 
  strcat(aux_string, kitchen_name);
  strcat(aux_string, at);
  sprintf(aux,"%d",int(luminC));
  strcat(aux_string, aux);
  strcat(aux_string, at);
  sprintf(aux,"%d",int(tempOutC));
  strcat(aux_string, aux);
  strcat(aux_string, at);
  sprintf(aux,"%d",int(tempInC));
  strcat(aux_string, aux);
  strcat(aux_string, at);
  sprintf(aux,"%d",int(humedC));
  strcat(aux_string, aux);
  delay(10);
  Serial.println(aux_string);
}

void showData(float iT, float eT, float h, float l){
  lcd.clear();
  lcd.setCursor(0, 0);
  lcd.print("Temp. Int:");
  lcd.setCursor(13, 0);
  lcd.print(iT,1);
  lcd.setCursor(19, 0);
  lcd.print("C");
  lcd.setCursor(0, 1);
  lcd.print("Temp. Ext:");
  lcd.setCursor(13, 1);
  lcd.print(eT,1);
  lcd.setCursor(19, 1);
  lcd.print("C");
  lcd.setCursor(0, 2);
  lcd.print("Humidity:");
  lcd.setCursor(13, 2);
  lcd.print(h,1);
  lcd.setCursor(19, 2);
  lcd.print(char(37));
  lcd.setCursor(0, 3);
  lcd.print("Luminosity:");
  lcd.setCursor(13, 3);
  lcd.print(l,0);
  lcd.setCursor(18, 3);
  lcd.print("LX");
}

//read all the sensors
void readSensors()
{
  tempInC = analogRead(tempInPin);           //read the value from the sensor
  tempInC = (supplyVolt * tempInC * 100.0)/1023.0;  //temp in
  tempInC = (tempInC-32)*5/9;
  delay(20);
  tempOutC = analogRead(tempOutPin);           //read the value from the sensor
  tempOutC = (supplyVolt * tempOutC * 100.0)/1023.0;  //change it the analog data to temperature
  evaluate_temp();
  delay(20);
  humedC = analogRead(humedPin);           //read the value from the sensor
  float voltage = humedC/1023. * supplyVolt; // change it to voltage value
  float sensorRH = 161.0 * voltage / supplyVolt - 25.8;
  //humedC = ((((humedC/1023)*5)-0.8)/3.1)*100;  //change it the analog data to HR%
  humedC = (sensorRH)/(1.0546-0.00216*(tempOutC)); // temperature compensation
  delay(20);

  luminC = analogRead(luminPin);           //read the value from the sensor
  evaluate_lumi();
  //luminC = (5.0 * luminC * 100.0)/1024.0;  //change it the analog data 
  Serial.println("=====================");
  Serial.print("Outside temperature: ");
  Serial.print(tempOutC,0); 
  Serial.println();
  Serial.print("Luminosity: ");
  Serial.print(luminC, 0); 
  Serial.print("  ");
  Serial.print(luminL);
  Serial.println();
  Serial.print("Humidity: ");
  Serial.print(humedC,0);
  Serial.println();
  Serial.print("Inside temperature: ");
  Serial.print(tempInC,0);  
  Serial.println();
}

//check the state of the buttons
void readButtons()
{
  bStartState = digitalRead(bStartPin);
  bFinishState = digitalRead(bFinishPin);  
  bDataState = digitalRead(bDataPin);

}

//check if the temperature is good enough to cook
void evaluateTemperature()
{
  if ((tempInC>60) && (!advicedHighTemp)){
  lcd.clear();
  lcd.setCursor(0,0);
  lcd.print("I'm above 60C");
  lcd.setCursor(0,1);
  lcd.print("when the food is inside");
  lcd.setCursor(0,2);
  lcd.print("press the");
  lcd.setCursor(0,3);
  lcd.print("green button");
  advicedHighTemp=true;
  }
}

void checkShowData()
{
   // check if the pushbutton is pressed.
  // if it is, the buttonState is HIGH:
  if ((bDataState == LOW) || (showState > 0)) {   
    delay(300);    
    showState = 1;
    showData(tempInC, tempOutC, humedC, luminC);
    delay(2000);

  } 
}

//check if the food is cooked
void checkStageTwo()
{
    if ((bFinishState == LOW)&&(stage == 2)){
    delay(300);
    lcd.clear();
    lcd.setCursor(0,0);
    lcd.print("Food ready!");
    delay(2000);
    lcd.clear();
    stage = 0;
  }  
}

//check if the kitchen is heating and ready to cook
void checkStageOne()
{
    if (bStartState == LOW){
    Serial.println("green button pressed");
    if (stage == 0){
      delay(300);
      lcd.clear();
      lcd.setCursor(0,0);
      lcd.print("Kitchen is");
      lcd.setCursor(0,2);
      lcd.print("heating");
      delay(3000);
      lcd.clear();
      stage = 1;
    }
    else if (stage == 1){
      delay(300);
      lcd.clear();
      lcd.setCursor(0,0);
      lcd.print("Cooking");
      delay(3000);
      lcd.clear();
      stage = 2;
    }
  }
}

//main
void loop()
{
  readSensors();
  delay(3000);
  generateUpdate();
  writeSD();
  memset(aux_string,0,sizeof(aux_string));
  addr1 = addr + 1;
  addr2 = addr + 2;
  addr3 = addr + 3;
  EEPROM.write(addr,(byte)tempOutC);
  delay(20);
  EEPROM.write(addr1, (byte)luminC);
  delay(20);
  EEPROM.write(addr2, (byte)humedC);
  delay(20);
  EEPROM.write(addr3, (byte)tempInC);
  delay(20);
  // advance to the next address.  there are 512 bytes in 
  // the EEPROM, so go back to 0 when we hit 512.
  addr = addr + 4;
  if (addr == 512)
    addr = 0;   

  readButtons(); 
  checkStageOne();
  checkStageTwo(); 
  checkShowData();
  evaluateTemperature();
  lcd.clear();
  
}

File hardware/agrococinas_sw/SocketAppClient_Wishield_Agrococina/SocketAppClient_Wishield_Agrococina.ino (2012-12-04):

        /*
        * Socket App
        *
        * A simple socket application example using the WiShield 1.0
        */

#include <WiShield.h>
#include <string.h>
extern "C" {   
    #include <uip.h>
}

    //    extern "C" int connectToServer(void);
           
#define WIRELESS_MODE_INFRA	1
#define WIRELESS_MODE_ADHOC	2

// Wireless configuration parameters ----------------------------------------
unsigned char local_ip[] = {192,168,1,242};	// IP address of WiShield
unsigned char gateway_ip[] = {192,168,1,1};	// router or gateway IP address
unsigned char subnet_mask[] = {255,255,255,0};	// subnet mask for the local network
const prog_char ssid[] PROGMEM = {"agrococina"};		// max 32 bytes

unsigned char security_type = 2;	// 0 - open; 1 - WEP; 2 - WPA; 3 - WPA2

// WPA/WPA2 passphrase
const prog_char security_passphrase[] PROGMEM = {"rhokbilbao"};	// max 64 characters


// WEP 128-bit keys
// sample HEX keys
prog_uchar wep_keys[] PROGMEM = {	0x01, 0x02, 0x03, 0x04, 0x05, 0x06, 0x07, 0x08, 0x09, 0x0a, 0x0b, 0x0c, 0x0d,	// Key 0
									0x00, 0x00, 0x00, 0x00, 0x00, 0x00, 0x00, 0x00, 0x00, 0x00, 0x00, 0x00,	0x00,	// Key 1
									0x00, 0x00, 0x00, 0x00, 0x00, 0x00, 0x00, 0x00, 0x00, 0x00, 0x00, 0x00,	0x00,	// Key 2
									0x00, 0x00, 0x00, 0x00, 0x00, 0x00, 0x00, 0x00, 0x00, 0x00, 0x00, 0x00,	0x00	// Key 3
								};
// setup the wireless mode
// infrastructure - connect to AP
// adhoc - connect to another WiFi device
unsigned char wireless_mode = WIRELESS_MODE_INFRA;

unsigned char ssid_len;
unsigned char security_passphrase_len;

// End of wireless configuration parameters ----------------------------------------

        boolean connectToServer(void);
       
        char            insert[] = "INSERT@43.29564@-2.99729@supercocina@2100000000@4@arroz";
        char            update[] = "UPDATE@micrococina@114@24.0@60.3@5100500000@stop";
        char            *toSend;
        unsigned char   server_ip[] = {192,168,1,73};
        unsigned int    ip_port   = 9999;
        unsigned int    xmitCount = 0;        
        boolean         connectedToServer = false;
        boolean         inited    = false;       
        boolean         firstTime = true;
        unsigned long   nextXMitTime;
        unsigned long   period_to_update = 60000;
       
        char            buffer[105];

        void setup()
        {
           Serial.begin(9600);       
           Serial.println("starting");             
           connectedToServer = false;             
           WiFi.init();       
        }

        void loop()
        {  
        
           WiFi.run();
           delay(200);
           
           if (millis() > nextXMitTime && inited && !connectedToServer) {
              Serial.print("Connecting to server... ");
              xmitCount = 0;
              if (connectToServer()) {
                  connectedToServer = true;
                  Serial.println("connection OK");
                  delay(200);
              }
              else {
                  Serial.println("connection NOT OK");
              }
           }                 
        }
       
        // Make the initial connection to the remote server at 192.168.0.2
        boolean connectToServer(void)
        {                       
           struct uip_conn *conn;
           uip_ipaddr_t ipaddr;
           
           uip_ipaddr(&ipaddr, server_ip[0],server_ip[1],server_ip[2],server_ip[3]);
           conn = uip_connect(&ipaddr, HTONS(ip_port));
           
          // uip_connect seems to never return NULL even in the case of a non-connect
          // Fortuantely you'll get a timeout if the connection is not good.
          // But it would be nice if this happened right away.
          return (conn != NULL);
        }
       
        // The 'extern "C"' allows these functions to be called directly by the framework.  You see the framework is
        // written in 'C' and Arduino code is compiled to C++.  The two are similar but not the same.
       
        // It's easer to have these functions here in the Arduino code because:
        // (1) You can use Serial.println commands
        // (2) Integration with other Arduino code is easier.
        // (3) No need to pass strings back and forth in large buffers.  String processing can be done directly on RX values

        extern "C" {
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

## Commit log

2012-11-30 Añadido el fichero .gitignore
2012-11-30 Añadido el README.md
2012-11-30 changed the client to support update and insert
2012-11-30 Insertion into Virtuoso.
2012-11-30 Insert and Update done.
2012-11-30 Añadido led + SD + log
2012-12-01 Paso a ArduinoMega completado
2012-12-04 Printable designs for the DIY solar panel casing
    [design v1.0.dwg, design v1.0.stl, design v2.0.dwg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]
2012-12-04 Arduino SW Updated
2012-12-04 third version of the DIY solar panel
    [design v3.0.dwg, design v3.1.stl, design v3.2.stl]
2013-01-16 moved SocketAppClient_Wishield_Agrococina second attempt
2013-05-13 the pdf files of schematics
